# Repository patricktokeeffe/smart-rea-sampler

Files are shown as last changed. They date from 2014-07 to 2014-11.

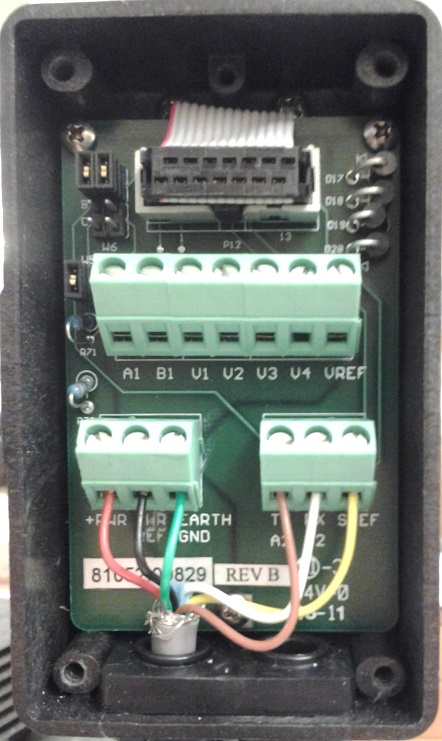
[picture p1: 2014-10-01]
doc/images/sonic_junction_box.jpg

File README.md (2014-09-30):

Long-term Trace Gas Flux Sampler
================================

Using the Relaxed Eddy Accumulation (REA) technique with canisters
------------------------------------------------------------------

> Project page: <https://bitbucket.org/wsular/sampler-rea-lt-canister>

A trace gas sampling system based on the relaxed eddy accumulation technique.
Large (33L) canisters are used as accumulation vessels. 

### License 

This work is licensed under [The MIT License](http://opensource.org/licenses/mit-license.html).

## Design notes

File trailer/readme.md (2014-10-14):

*Trailer-mounted off-grid power system stuffs*

* CAD drawings of
    * window cut into lid of 4x6 plastic project box
    * wood box constructed on small trailer

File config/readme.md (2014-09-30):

*Sensor configuration files*

* GPS :: If the Garmin GPS16x-HVS was not purchased from Campbell Scientific, 
  it must undergo a one-time configuration for use with the datalogger. The
  software required is available for free (see `gps_software_links.txt`) and
  the required settings are saved to an importable format (`gps_settings.cfg').

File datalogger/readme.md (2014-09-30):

Sensors are wired to datalogger as specified in the OpenDocument Spreadsheet 
`wiring_table.ods`. A PDF copy may be obtained from 
[this page](https://bitbucket.org/wsular/sampler-rea-lt-canister/downloads).

The program `default.cr3` is loaded onto the "brains" of the system, a model
CR3000 datalogger produced by Campbell Scientific Inc.

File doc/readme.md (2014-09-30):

This folder contains source files for the user manual. Additional resources 
are available in the `../datalogger`, `../engr`, and `../third-party` folders.

Compiling the user manual requires [Lyx 2.1](https://www.lyx.org). 
Pre-compiled PDF copies of the user manual are available on the project
[downloads](https://bitbucket.org/wsular/sampler-rea-lt-canister/downloads) 
page.

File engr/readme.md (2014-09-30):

*The engineering folder*

* **bill_of_materials.xlsx** is an Excel&trade; spreadsheet listing system
  components, vendors, and prices grouped by category.
* **block_diagrams.odg** contains schematics of various subsystems in block
  format.
* **calculations.xlsx** is an Excel&trade; spreadsheet with various related 
  quantitative analyses. Calculations are categorized and linked across
  worksheets to simplify & facilitate exploration.
    * *Conditions:* environmental conditions specified here
    * *Canisters:* determine actual orifice flow, expected canister fill level
      and potential sampling duration based on canister specs and operating
      conditions
    * *Flow:* **(outdated)** evaluate flow characteristics like delay time,
      [Reynolds #](https://en.wikipedia.org/wiki/Reynolds_number#Transition_and_turbulent_flow),
      frictional pressure drop, and target design pressure downstream of 
      critical orifices
    * *Consumption:* tally the power consumption and duty cycle of components
      to determine power requirements
    * *PV system:* determine required number of solar panels and batteries
      based on their specifications, system power requirements, and operating 
      conditions
    * *Batteries:* derive an expression for battery capacity as a function of
      current draw for use in *PV system* worksheet
* **design_discussion.pptx** is a PowerPoint&trade; document with summary-level
  discussion of the gas sampling design

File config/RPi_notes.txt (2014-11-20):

Raspberry Pi configuration notes
================================

config.txt
----------

* Default user name is "pi" and password is "raspberry" -- root account is 
  disabled so use 'sudo' or 'gksu' when necessary

The suggested `config.txt` was sourced from Adafruit, the vendor.
    https://www.adafruit.com/products/1928
    https://web.archive.org/web/20140930223220/https://www.adafruit.com/products/1928

Real-time clock (RTC) construction
----------------------------------

* Omit the resistors so the module communicates at 3.3V instead of 5V
* Fortuitously all signals are adjacent in the ribbon cable:
    * Pin 3: SDA1
    * Pin 4: 5V
    * Pin 5: SCL1
    * Pin 6: Ground
* Cut cable and split apart so pins 1 & 2 constitute one 'cable' (will be used
  for comms w/ Tri-meter), pins 3-6 are connected as another 'cable' and
  remainder of ribbon cable is left alone for now
* To faciliate easy connect/disconnect, use 4-pc PCB-mount screw terminal block
* Mount on one end of small rectangular IC-style RadioShack PCB; other end will
  be used to mount components for communicating with Trimetric

Initial setup
-------------

For initial setup, connection to internet is required to pull updates and
packages. At WSU, need wifi dongle since wired LAN implements MAC filtering.

* Default local is Great Britain, which does funny things to keyboard layout so
  change to US locale
* Enable I2C support for real-time clock comms (two-part process)

* Run `$ sudo raspi-config` 
    * Under (4) Internationalisation
        * change local from 'en_GB UTF8' to 'en_US UTF8'
        * change timezone to 'US > Pacific-New'
        * change keyboard layout from 'English (UK)' to 'Other > English (US) > English (US)'
            * leave AltGr as default for layout
            * no compose key
            * yes, enable Ctrl+Alt+Bckspc to exit X server
    * Under (8) Advanced Options
        * A6 I2C: change from 'no' to 'yes'
        * A7 Serial: change output message to serial port during boot from 'yes' to 'no'
* Follow Adafruit GPIO setup instructions to finish enabling I2C support
* Follow Adafruit Adding a RTC tutorial to finish integrating RTC w/ RPi

General environment setup
-------------------------

* Get `pip`: run `$ sudo apt-get install python-pip`

Communicating with TriMetric
----------------------------

* Ignore mnfctr's instructions, just use pins 3/4 on trimetric
    * Tie Trimetric and RPi ground together
* DO run signal output through 5->3.3 level converter
* No need to connect transmit from Pi (Trimetric has no Rx)

Communicating with SureSine
---------------------------

* Device uses MODBUS RTU protocol (after switching jumper #4 ON)
* To get Python support for MODBUS run `$sudo pip install -U minimalmodbus`
* `minimalmodbus` uses default baudrate of 115200, must be changed to 9600
* Logical addresses are one greater than real addresses (0x0000=1, 0x0001=2, ...)
  and must be entered as decimal (0x000A=10, 0x000B=11, ...)

Improve usability by enabling VNC server
----------------------------------------

* Follow Adafruit lesson installing/setting up `tightvncserver`; the display
  number specified at launch (":1" argument) causes incoming connections to
  be accepted on port 5900+# (e.g. :1 -> 5901)
* Must configure wired ethernet port (eth0) to use static IP (192.168.174.252)
  so cross-over cable connection is straight-forward
    * <http://www.stuffaboutcode.com/2012/05/raspberry-pi-setting-static-ip-address.html>
    * <http://elinux.org/RPi_Setting_up_a_static_IP_in_Debian>
    * Only include address & netmask under static settings
    * DO need to reboot RPi for settings to take effect

Display mounting
----------------

Resources on the display:
    Overview: https://learn.adafruit.com/hdmi-uberguide/1928-5-display-no-touch-w-slash-mini-driver-800x480-hdmi
    Driver board: https://learn.adafruit.com/hdmi-uberguide/mini-rtd2660-hdmi-driver-board

Concerning the HDMI display buttons:
    Remote control idea: https://forums.adafruit.com/viewtopic.php?f=31&t=53407&p=269909&hilit=button+display+mount#p269909
    Glued pegs/Sugru suggestion: https://forums.adafruit.com/viewtopic.php?f=31&t=34618&p=171226&hilit=button+display+mount#p171226

RS-232 interfacing
------------------

* ~~USB-RS232 converter (Adafruit product 18, discontinued) operates at +/-10Vdc
  which makes it ideal for use with True RS-232 on Inverter's serial dongle
  but NOT okay for communicating via built-in UARTs -- get serial debug cable
  (Adafruit product 954) instead~~ Per MorningStar Connectivity Manual, the
  voltage output of serial ports on MorningStar products is below the RS-232 
  electrical specification so no need to use a special USB-serial adapter with
  SureSine's serial adapter

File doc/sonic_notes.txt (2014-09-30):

- Connect sonic to computer using default serial config: 38400/8/N/1
- Enter menu by sending escape (0x1B) several times
- Change these settings
    * E) Error Handling: 2 -> 1 (exclude -> include invalid data)
    * O) Output rate: 4 -> 10 Hz
    * S) Serial output format: press 1/Custom, 789AB -> 5BE (UVW, Ts, Err code)

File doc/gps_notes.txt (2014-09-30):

- Garmin GPS was purchased from Amazon.com and did not come configured for use
  with CR3000 datalogger
- Connect GPS to computer using RS-232/USB converter, 12Vdc adapter and a
  device built previously but not well documented --> TODO
- Begin communication with GPS using "SNSRXCFG.exe" (v2.90)
    * autodetected device at 4800 baud
    * changed settings:
        ~ baud rate 4800 --> 38400
        ~ disable 'Position averaging' (position pinning = averaging per communication w/ CSI)
    * disabled GPGSA, GPGSV, PGRMT; leaves only GPGGA, GPRMC
    * saved new target settings to 'SNSRXCFG.cfg'
    * sent new settings to device
- Tested, confirmed to work with CR3000
- Remove violet, green wires and tin remaining wires

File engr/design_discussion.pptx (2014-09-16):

## Design Updates: September 15, 2014

- Most of the components have arrived; remaining items:
  - PV system
    - solar panels
    - charge controller
    - cables, switches/breakers
    - Mounting hardware
  - Trailer (for PV array + batteries & transporting system)
  - Pump (discussion follows)
  - (?) Pressure gage (following pump discussion)
- Major decision:
  - retain single tube with subsampling into canisters (high power consumption)
  - or sample directly from atmosphere into canisters (low power consumption)

## Under current design:

To ensure turbulent flow in single tube, minimum flow rate (L/min):

Tube size | @ Sea level | Pullman | Denver
Standard ¼” | 11.2 | 12.5 | 13.6
Thick-wall ¼” | 9.1 | 10 | 11
Standard 1/8” | 2.3 | 2.5 | 2.7

To ensure choked flow across orifice, max. downstream pressure (mbar):

Based on.. | @ Sea level | Pullman | Denver
Pressure drops | 484 | 437 | 350
Canister fill safety margin | 434 | 395 | 357

Target pump operating conditions: 2.5 L/min at 400 mbar

## Pump candidates:

Choice assumed in ‘Consumption’ spreadsheet

Mnfctr | Model | Power | Type | Notes
KNF | NPK09DC | 62W | Diaphragm | Barely meets operating conditions
KNF | NPK 018…DC | 130W | Diaphragm | Moderate operating margin
Gast | 15D1150-101-1006 | 13W | Diaphragm | Barely meets operating range; power specs are suspiciously optimistic
Gast | 22D1180-201-1002 | 96W | Diaphragm | Narrow operating margin
Gast | 1531-107B-G617 | 170W | Rotary vane | Very wide operating margin; power specs missing, reported value is from pump with similar characteristics
Gast | LOA-101-JR | ~120W | Rocking piston | Moderate operating margin Power specs are 11-15V @ 9A Finicky: temp range (5-40 ºC), RH range (20-80%)
Gast | ROA-V210-JH / ROA-P201-JH | 170W | Rocking piston | Wide operating margin; Finicky: temp range (5-40 ºC), RH range (20-80%)
Air Dimensions | J161-xx-HH0 | 29W | Diaphragm | Barely almost hardly meets operating conditions
Air Dimensions | 201-xx-JH0 | 460W | Diaphragm | Barely meets operating conditions; power specs missing, reported value is from 222 series (dual head version of 221-)
Air Dimensions | 221-xx-JH0 | 460W | Diaphragm

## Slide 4

With indicated pump choice, the solar array would need to be about 1000W to provide 365/24/7 operation. However:
- pump indicated is probably insufficient to achieve turbulent flow
- larger pump raises the req'd array size EX: the other KNF model listed is 130W -> raises array to 1800W
Can we lower system power consumption to minimize solar array size?
- Sure, mitigation strategies include:
  - Seasonal instead of year-round operation
  - Not operating at night
  - Bye-days
  - Deploy at lower latitudes (this is destined for CA, right?)
- Other ideas:
  - Modify sampling configuration (discussion begins next slide)
  - Automatic generator back-up (yuck)
  - Small wind-turbine generator (except for possibly disrupting wind field?)

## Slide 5

One alternative:

- move orifices/3-way valves to sampling location (diagram)
- use small dual-head pump to draw air across orifices such as Brailsford TD-4X2N (pictured)
  - with heads in series, it produces sufficient vacuum for choked flow (measured @ -19 in Hg ≈ -650 mb)
  - small power consumption (0.4A @ 9-14Vdc) eliminates need to power pump directly off PV array batteries

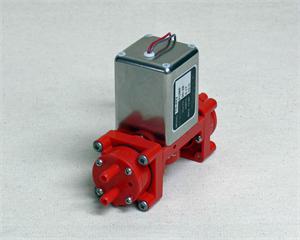
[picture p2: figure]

to pump
(normally open)

negligible-length
1/8" leader tube

orifice (common)

Buy another pressure sensor?:
To detect pump/diaphragm failure, and to ensure sufficient vacuum is present for choked flow, add a pressure sensor between each pump & 3-way valve.
One electronic 0-15 psia gage (Omega PX309-015G5V) is available but one more would be required at an estimated $240.

to canister
(normally closed)

P

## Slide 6

Relocating orifice/3-way valve assembly to near sonic sampling volume introduces volume between canister & orifice. However, this volume is negligible.
Even under the following assumptions, volume of tube from 3-way valve to canister is less than 1% of actual volume in canister:
- 10% safety margin (canister filled to 42.8% of capacity or about 14 std L)
- 30 ft of standard 1/4" tubing
With 20 ft of 1/8" standard, volume in tubing is 0.02% of final sample volume.

Volume (mL) as a function of tube size, length:

Tube size | 10 ft | 15ft | 20 ft | 25 ft | 30 ft
Standard 1/4" | 37 | 56 | 75 | 94 | 113
Thick-wall 1/4" | 25 | 37 | 49 | 61 | 74
Standard 1/8" | 1.5 | 2.2 | 3.0 | 3.7 | 4.5

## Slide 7

Smart REA Sampler
Collection Mode

- Identical systems for ‘up’ and ‘down’ sampling.
- Critical orifice mounts in common side of solenoid valve.
- Pressure gauge #1 needs to work across wide range… something like <0.1 psia to 30 psia.
- Pressure gauge #2 operates under vacuum, so general purpose 0-15 psia is satisfactory.
- Manual valves must be leak tight in vacuum, and solenoid must seal under same conditions.
- Tubing downstream of solenoid is 1/8" Teflon.
- Fittings from valve(s) to canister are stainless steel.
- Filter probably needed upstream of pump (not shown).

Air parcel

Switching

3

P2

To
Pump

Open

P1

Open

Closed

Sampling
Canister

Legend
Manual, High Integrity On/Off Valve
High Precision Critical Orifice
High Precision Vacuum/Pressure Gauge
Fast, Low Dead Space Three-Way Valve

P

3

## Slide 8

Open to Pump

Smart REA Sampler
Pressurization Mode

3

To
Pump

Closed
to Pump

P2

From
Regulated
Gas Cylinder

Closed

- After sampling period, canister is filled to ~30 psi with UHP nitrogen.
- Pressure gauge records pressure change so that the dilution factor is precisely known.

P1

Open

Open

Sampling
Canister

Legend
Manual, High Integrity On/Off Valve
High Precision Critical Orifice
High Precision Vacuum/Pressure Gauge
Fast, Low Dead Space Three-Way Valve

P

3

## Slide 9

Open to Pump

Smart REA Sampler
Transfer Mode

- Pressurized main canister is used to fill several smaller canisters/cartridges.
- Cartridges are attached in parallel so that all are filled to same pressure.
- Cartridges can be then transferred to laboratory for analysis.
- Pressure gauge records pressure change so that the cartridge pressures are known.
- Cartridge design still TBD.

Legend
Manual, High Integrity On/Off Valve
High Precision Critical Orifice
High Precision Vacuum/Pressure Gauge
Fast, Low Dead Space Three-Way Valve

3

To
Pump

Closed
to Pump

Closed
to Pump

Closed

P2

To
Pump

To Smaller
Evacuated
Cartridges

P1

Open

Open

Sampling
Canister

P

3

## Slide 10

Open to Pump

Smart REA Sampler
Evacuation Mode

3

To
Pump

Closed
to Pump

Closed
to Pump

Open

P2

To
Pump

To Suitable
Vacuum
Pump

- Vacuum pump must be able to evacuate system to near vacuum (< 0.1 psi = 7 mb).
- ~~Solenoid also evacuated to minimize contamination.~~

P1

Open

Open

Sampling
Canister

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

P

3

## Design Updates: June 11, 2013

- Contacted Tom Jobson & Claudia Toro about borrowing canisters. Claudia will work with Korey to get trained up on how to evacuate/fill them.
- New design for the switching mechanism. Swapped critical orifice with switching valve and changed switching valve to three-way valve. Other arm of three-way valve will be tied to vacuum pump.
  - Flow will be passing through the critical orifice at all time, addressing concern about transient flows through the orifice.
  - Dead volume less of a concern now. Instead, we just need to have a very good understanding of the expected travel time from the tower top to the three way valve. Note Patrick’s concern below.
- Patrick O’Keefe asked how we “anticipate handling the time delay between the measurement of an up/down eddy at the sonic and the switching of the appropriate valve down at the canister? Will the flow be regulated well-enough to use a static pre-calculated delay time? Seems like the switching should occur at the sonic to avoid that ambiguity.”

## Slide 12

From
Tower

Smart REA Sampler
Collection Mode

- Identical systems for ‘up’ and ‘down’ sampling.
- Need to minimize dead volume between solenoid and critical orifice.
- Pressure gauge needs to work across wide range… something like <0.1 psi to 30 psi.
- Manual valves must be leak tight in vacuum, and solenoid must seal under same conditions.
- All tubing & fittings downstream of solenoid are stainless steel.
- Filter needed upstream of solenoid (not shown).

OLD DESIGN 1

To
Pump

S

P

Sampling
Canister

Open

Open

Closed

Switching

Legend
Manual, High Integrity On/Off Valve
High Precision Critical Orifice
High Precision Vacuum/Pressure Gauge
Fast, Low Dead Space Solenoid Valve

P

S

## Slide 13

From
Tower

Smart REA Sampler
Collection Mode

- Identical systems for ‘up’ and ‘down’ sampling.
- Need to minimize dead volume between solenoid and critical orifice.
- Pressure gauge needs to work across wide range… something like <0.1 psi to 30 psi.
- Manual valves must be leak tight in vacuum, and solenoid must seal under same conditions.
- All tubing & fittings downstream of solenoid are stainless steel.
- Filter needed upstream of solenoid (not shown).

OLD DESIGN 2

To
Pump

Switching

3

To
Pump

Open

P

Open

Closed

Sampling
Canister

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

P

3

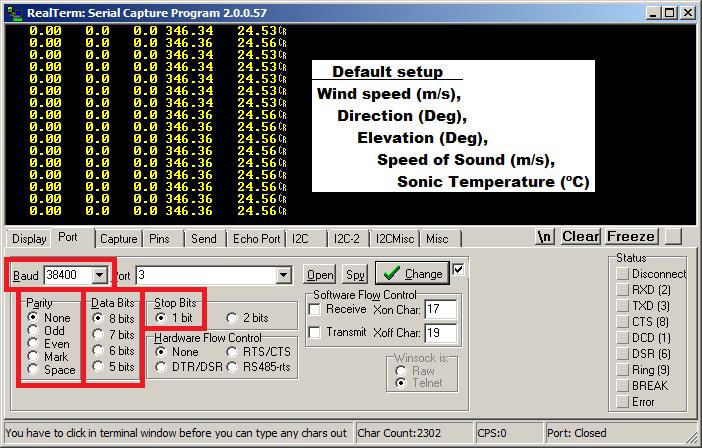
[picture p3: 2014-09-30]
doc/images/sonic_defaults.png

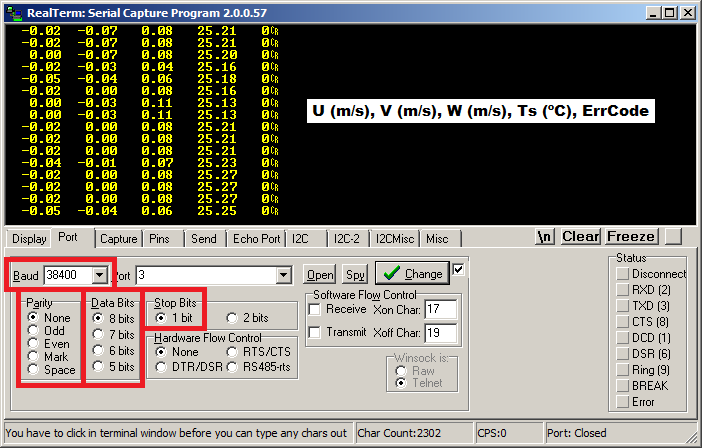
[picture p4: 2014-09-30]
doc/images/sonic_settings.png

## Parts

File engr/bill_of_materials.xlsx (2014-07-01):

Component List for REA/Canister System
 |  |  |  | Total ($): | $19689.57
Description | Qnty | Vendor (Mnfctr if diff.) | Model / Part no. | Unit price ($) | Ext. price ($) | Price as of | Notes | Online
Anemometer, 3D ultrasonic | 1 | RM Young | 81000VRE | 3390 | 3390 |  |  | http://www.youngusa.com/products/6/46.html
Canisters, SS, 33L | 2 | LabCommerce Inc | X133L | 1700 | 3400 | 2014-06-27 |  | http://www.labcommerce.com/airsamp_viewproducts.php?catid=17
Critical orifice, screened sapphire, 6sccm | 2 | O'Keefe Controls | JSS-3-SS | 37.5 | 75 | 2013-07-02 |  | http://www.okcc.com/catsub_precision.htm
Data logger | 1 | Campbell Scientific | CR3000-ST-SW-RC-NC | 3235 | 3235 |  |  | http://www.campbellsci.com/cr3000
Data logger memory/ethernet module | 1 | Campbell Scientific | NL115-ST-SW | 290 | 290 |  |  | http://www.campbellsci.com/nl115
Datalogger charger: 12->24V | 1 | Digikey (CUI Inc) | 102-3188-ND | 44.48 | 44.48 | 2014-06-27 |  | http://www.digikey.com/product-detail/en/PYB15-Q24-S24-T/102-3188-ND/4477446
Datalogger support software, PC400 | 1 | Campbell Scientific | PC400 |  | 0 |  | *Ask Patrick
Enclosure for canisters | 1 | Home Depot (Rubbermaid) | 1863391 | 224 | 224 | 2014-06-27 | "Rattan Patio Cabinet" | http://www.homedepot.com/p/Rubbermaid-Rattan-Patio-Cabinet-1863391/204725829?N=5yc1vZbtz1
Enclosure for datalogger | 1 | Campbell Scientific | ENC12/14 |  | 0 |  |  | http://www.campbellsci.com/enc-12-14-overview
Enclosure for MFC + valve relays | 1 | Walmart (Plano) | Guide Series Poly. Box, Large | 39.99 | 39.99 | 2014-06-27 |  | http://www.walmart.com/ip/Plano-Guide-Series-PolyCarbonate-Box-Large-Blue/20563433
Fittings, assorted | 1 | Swagelok |  | 200 | 200 | -- n/a --
Fittings: cross, 1/4" | 2 | Swagelok | SS-400-4 | 42.54 | 85.08 | 2014-06-27
Fittings: |  | Swagelok |  |  | 0
Fittings: |  | Swagelok |  |  | 0
Fittings: port connectors, 1/4" | 8 | Swagelok | SS-401-PC | 5.9 | 47.2 | 2014-06-27
Fittings: tee, 1/4" x 1/4" FNPT x 1/4" | 2 | Swagelok | SS-400-3-4TTF | 33.74 | 67.48 | 2014-06-27
Fittings: union, 1/4" x 1/8" MNPT | 4 | Swagelok | SS-400-1-2BT | 8.18 | 32.72 | 2014-06-27
Fittings: union, bulkhead, 1/4" | 2 | Swagelok | SS-400-61 | 17.08 | 34.16 | 2014-06-27
GPS receiver | 1 | Amazon (Garmin) |  | 89 | 89 | 2014-06-27 | For precision time source | http://www.amazon.com/Garmin-010-00258-63-GPS-16x-HVS/dp/B0016NYHSG
GPS receiver magnetic mount | 1 | Amazon (Garmin) |  | 13 | 13 | 2014-06-27 |  | http://www.amazon.com/Garmin-010-10302-00-Magnetic-mount/dp/B00006B6MD/ref=pd_bxgy_e_text_y
Mass flow controller | 1 | Alicat Scientific | MC-20SLPM-D | 1330 | 1330
Mass flow controller AC/DC adapter | 1 | Alicat Scientific | PVPS24U | 52.25 | 52.25
Mass flow controller data cable | 1 | Amazon (Cables2Go) | 02318 | 7.62 | 7.62 | 2014-06-27 | 8-pin mini DIN | http://www.amazon.com/C2G-Cables-02318-Mini-Din-Charcoal/dp/B0002GWN84
Mass flow controller pre-filter | 1 | Swagelok | SS-4F-40 | 77.83 | 77.83 | 2014-06-27
Memory card, CompactFlash, 8GB | 2 | California PC |  | 154 | 308 | 2014-06-27 |  | http://www.californiapc.com
Pressure sensor, 0-30psia, 0-5V output | 2 | Omega | PX409-030A5V | 525 | 1050 |  |  | http://www.omega.com/pptst/PX409_Series.html
Pressure snubber | 2 | Omega | PS-4G | 13 | 26 |  |  | http://www.omega.com/pptst/PS_SNUBBERS.html
Pump, 12Vdc | 1 | KNF Inc. | NPK09DC | 400 | 400
Relay, 5-60Vdc output, 0-5Vdc logic | 2 | Opto22 | ODC5 | 16 | 32 | 2014-06-30 | For valve control | http://opto22.com/site/pr_details.aspx?cid=7&item=ODC5
Relay mounting board | 1 | Opto22 | PB4R | 45 | 45 | 2014-06-27
Relay, solid state, 5-60Vdc output, 0-5Vdc logic | 1 | Crydom |  | 0 | 0 | 2014-06-30 | For pump on/off
Relay, solid state, cover | 1 |  |  |  | 0
Solar array battery bank package | 1 | Wholesale Solar | 1898531 | 1543 | 1543 | 2014-06-30
Solar charge regulator | 1 | MorningStar | SS-10L-12V | 75 | 75
Solar panels | 2 | Wholesale Solar |  |  | 0
Temp/RH sensor | 1 | Campbell Scientific (Vaisala) | HMP155A-L20 | 685 | 685 |  |  | http://www.campbellsci.com/hmp155a
Temp/RH sensor radiation shield | 1 | Campbell Scientific (RM Young) | 41005-5 | 200 | 200 |  |  | http://www.campbellsci.com/h41005-5
Tower, 3m | 1 | Campbell Scientific | UT10 | 565 | 565 |  |  | http://www.campbellsci.com/ut10
Tubing, PFA, 1/4" OD (0.047" wall), 100 ft | 1 | Swagelok |  | 270 | 270 | 2014-06-27
Tubing, PFA, 1/4" OD (0.047" wall), 100 ft | 1 | Savillex | 760-1-156-250-100 | 327.6 | 327.6 | 2014-06-27
Valve, diaphragm, manual, two-way | 6 | Swagelok | 6LVV-DPRS4 | 203.69 | 1222.14 | 2014-06-27 | For canisters
Valve, solenoid, 12V, three-way, fast-acting | 2 | Paramount Supply (Asco) | 8320G041DC12/DCD | 103.01 | 206.02 |  | For conditional eddy sampling
 |  |  |  |  | 0
 |  |  |  |  | 0
 |  |  |  |  | 0
 |  |  |  |  | 0
Valve, solenoid, 12V, three-way, fast-acting | 0 | Parker-Hannifin | 091-0094-900 | 285 | 0 | 2012-07-18
Tubing, PFA, 1/8" OD (1/16" ID), 100' | 0 | Savillex | 760-1-062-125-100 | 171.6 | 0 | 2014-06-27 |  | http://www.savillex.com/ProductDetail.aspx?ProductName=Coiled-tubing-PFA-116-ID-x-18-OD-100
 |  |  |  |  | 0
 |  |  |  |  | 0
 |  |  |  |  | 0
 |  |  |  |  | 0
 |  |  |  |  | 0
 |  |  |  |  | 0
 |  |  |  |  | 0
 |  |  |  |  | 0
 |  |  |  |  | 0

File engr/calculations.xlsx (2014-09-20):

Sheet: Conditions
Reference
Barometric pressure
sea level | 1013 | mbar
Pullman (2550') | 923 | mbar
Denver (5280') | 834 | mbar
User Input
Ambient temperature | 55 | ºF
Barometric pressure | 923 | mbar

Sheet: Canisters
Conditions
Ambient temperature | 55 | ºF
Barometric pressure | 923 | mbar
User Input
Orifice flow @ STP | 6 | sccm
Canister volume | 33 | liters
Canister full safety margin | 10%
Deadband | 0.85 | (multiplier)
Sampling hours per day | 24 | hrs
Derived Values
Actual orifice flow | 6.4 | cc/min
Fraction of time in deadband | 60.46749138%
Fraction of time per canister | 19.76625431%
Canister fill time | 7.75 | days

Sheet: Flow
 |  |  | Flow | Velocity | Delay | Delay (# scans) |  |  | Friction
Conditions |  |  | L/min | m/s | s | 10Hz | 20Hz | Reynolds # | factor | ΔP (mbar) | ΔF (%)
Ambient temperature | 55 | ºF | 1 | 34.22680103 | 0.18 | 1.8 | 3.6 | 1682.824725 | 0.049 | 2.15 | 1.20
Barometric pressure | 923 | mbar | 1.5 | 51.34020154 | 0.12 | 1.2 | 2.4 | 2524.237087 | 0.045 | 1.94 | 0.80
 |  |  | 2 | 68.45360206 | 0.09 | 0.9 | 1.8 | 3365.649449 | 0.041 | 1.81 | 0.60
Reference |  |  | 2.5 | 85.56700257 | 0.07 | 0.7 | 1.4 | 4207.061811 | 0.039 | 1.71 | 0.48
Pressure drop across MFC | 7 | psi | 3 | 102.6804031 | 0.06 | 0.6 | 1.2 | 5048.474174 | 0.037 | 1.63 | 0.40
Tubing size | I.D. |  | 3.5 | 119.7938036 | 0.05 | 0.5 | 1.0 | 5889.886536 | 0.036 | 1.57 | 0.34
1/4" (0.047) | 0.156 | in | 4 | 136.9072041 | 0.04 | 0.4 | 0.9 | 6731.298898 | 0.035 | 1.52 | 0.30
1/4" (0.062) | 0.126 | in | 4.5 | 154.0206046 | 0.04 | 0.4 | 0.8 | 7572.71126 | 0.034 | 1.47 | 0.27
1/8" (0.047) | 0.031 | in | 5 | 171.1340051 | 0.04 | 0.4 | 0.7 | 8414.123623 | 0.033 | 1.44 | 0.24
 |  |  | 5.5 | 188.2474057 | 0.03 | 0.3 | 0.6 | 9255.535985 | 0.032 | 1.40 | 0.22
User input |  |  | 6 | 205.3608062 | 0.03 | 0.3 | 0.6 | 10096.94835 | 0.032 | 1.37 | 0.20
Tubing inner diameter | 0.031 | in | 6.5 | 222.4742067 | 0.03 | 0.3 | 0.5 | 10938.36071 | 0.031 | 1.35 | 0.18
Tubing length | 20 | ft | 7 | 239.5876072 | 0.03 | 0.3 | 0.5 | 11779.77307 | 0.030 | 1.32 | 0.17
ΔP across valve | 50 | mbar | 7.5 | 256.7010077 | 0.02 | 0.2 | 0.5 | 12621.18543 | 0.030 | 1.30 | 0.16
Turbulence threshold (Re#) | 4100 |  | 8 | 273.8144082 | 0.02 | 0.2 | 0.4 | 13462.5978 | 0.029 | 1.28 | 0.15
 |  |  | 8.5 | 290.9278087 | 0.02 | 0.2 | 0.4 | 14304.01016 | 0.029 | 1.26 | 0.14
Derived values |  |  | 9 | 308.0412093 | 0.02 | 0.2 | 0.4 | 15145.42252 | 0.028 | 1.24 | 0.13
Air temperature | 12.8 | degC | 9.5 | 325.1546098 | 0.02 | 0.2 | 0.4 | 15986.83488 | 0.028 | 1.22 | 0.13
Density of air | 1.125 | kg/m^3 | 10 | 342.2680103 | 0.02 | 0.2 | 0.4 | 16828.24725 | 0.028 | 1.21 | 0.12
Dynamic viscosity of air | 1.800940656e-05 | Pa*s | 10.5 | 359.3814108 | 0.02 | 0.2 | 0.3 | 17669.65961 | 0.027 | 1.19 | 0.11
Tubing cross-section area | 0.0008 | in^2 | 11 | 376.4948113 | 0.02 | 0.2 | 0.3 | 18511.07197 | 0.027 | 1.18 | 0.11
Tubing volume | 2.97 | mL | 11.5 | 393.6082118 | 0.02 | 0.2 | 0.3 | 19352.48433 | 0.027 | 1.17 | 0.10
Tubing volume fraction | 0.02% |  | 12 | 410.7216123 | 0.01 | 0.1 | 0.3 | 20193.89669 | 0.027 | 1.15 | 0.10
ΔP across MFC | -482.58 | mbar (diff) | 12.5 | 427.8350129 | 0.01 | 0.1 | 0.3 | 21035.30906 | 0.026 | 1.14 | 0.10
ΔP across orifice+valve | -485.656 | mbar (diff) | 13 | 444.9484134 | 0.01 | 0.1 | 0.3 | 21876.72142 | 0.026 | 1.13 | 0.09
Max pressure for choked flow | 487.344 | mbar (abs) | 13.5 | 462.0618139 | 0.01 | 0.1 | 0.3 | 22718.13378 | 0.026 | 1.12 | 0.09
Max pressure @ pump inlet | 435.636001 | mbar (abs) | 14 | 479.1752144 | 0.01 | 0.1 | 0.3 | 23559.54614 | 0.026 | 1.11 | 0.09
Max pressure @ canisters | 395.044 | mbar (abs) | 14.5 | 496.2886149 | 0.01 | 0.1 | 0.2 | 24400.95851 | 0.025 | 1.10 | 0.08
Target design pressure | 395.044 | mbar (abs) | 15 | 513.4020154 | 0.01 | 0.1 | 0.2 | 25242.37087 | 0.025 | 1.09 | 0.08
Constants
Gas constant, dry air | 287.058 | J/(kg K)
Sutherland's formula (air): C | 120 | K
Sutherland's formula (air): λ | 1.512041288 | (μPa*s)/K^-1/2
Choked flow ratio (P2/P1) | 0.528
Unit conversion: mbar/kPa | 10 | unity
Unit conversion: mbar/psi | 68.94 | unity
Unit conversion: in/m | 39.37 | unity
Unit conversion: s/min | 60 | unity
Unit conversion: L/m^3 | 1000 | unity
Unit conversion: in/ft | 12 | unity
Unit conversion: ft/m | 3.281 | unity
Unit conversion: Pa/kPa | 1000 | unity
Unit conversion: mL/in^3 | 16.387064 | unity

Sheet: Consumption
 |  |  |  |  |  |  | Running power | 17.55962054 | W
 |  |  |  |  |  |  | Standby power | 3.132 | W
Component | Model (Make) | Rating description | Qnty | Volts | Amps | Power, W | Run time | Total, W
Datalogger | CR3000 | 10-16Vdc; current depends | 1 | 12 | 0.010 | 0.12 | 100% | 0.12 | Core devices
Datalogger ethernet module | NL115 | depends; worst case: 43 mA @ 12Vdc | 1 | 12 | 0.043 | 0.516 | 100% | 0.52
GPS receiver | GPS16x-HVS | 8-40Vdc @ 65mA | 1 | 12 | 0.065 | 0.78 | 100% | 0.78
Pressure sensor | PX409-030A5V | 10-30Vdc @ 10mA | 2 | 12 | 0.010 | 0.12 | 100% | 0.24
Solar regulator | SunSaver | per CSI tech note: 6-10 mA continuously | 1 | 12 | 0.010 | 0.12 | 100% | 0.12
Sonic anemometer | 81000VRE | 12-24Vdc @ 110mA max | 1 | 12 | 0.110 | 1.32 | 100% | 1.32
Temp/RH sensor | HMP155A | 7-28Vdc @ <=3mA | 1 | 12 | 0.003 | 0.036 | 100% | 0.04
Fast-acting valve | (Parker) | 12Vdc @ 1000mA | 2 | 12 | 1.000 | 12 | 19.76625431% | 4.74 | Off in stand-by
Valve control relay | ODC5 | 12mA @ logic voltage (1mA off-state leakage) | 2 | 5 | 0.012 | 0.06 | 19.76625431% | 0.02
Pump control relay | ODC5 | 12mA @ logic voltage (1mA off-state leakage) | 1 | 5 | 0.012 | 0.06 | 100% | 0.06
Pump | Brailsford | 9-14Vdc @ 0.4A | 2 | 12 | 0.400 | 4.8 | 100% | 9.60

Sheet: PV system
Max consumption | 17.6 | W | Temp. derating multiplier [1] |  |  | Reference
 | 1.5 | Amps | Degrees | Degrees |  |  | sun hours/day
Standby consumption | 3.1 | W | F | C | Multiplier | Location | annual mean | winter
 | 0.3 | Amps | 80 | 26 | 1 | Pullman, WA | 4 | 2 | [5, 6], [4]
 |  |  | 70 | 21.2 | 1.04
 |  |  | 60 | 15.6 | 1.11
Operating conditions |  |  | 50 | 10 | 1.19
Running hours of pump per day | 24 | hr/day | 40 | 4.4 | 1.3
Watt hours needed per day | 421.430893 | W*hr/day | 30 | -1.1 | 1.4
 |  |  | 20 | -6.7 | 1.59
Battery bank requirement [1,2] |  |  | Selected battery characteristics
Battery bank voltage | 12 | V | Type | Rolls Surrette S-550
Days without sun | 10 | days | Voltage | 6 | Volts
Depth of discharge | 50% |  | Amp-hour | 726.7489942 | Ahr
Temperature multiplier | 1.59 |  | Number of | 4 | batteries
Battery bank size | 1116.791866 | A*hr | Total reserve | 1453.497988 | Ahr
 |  |  | Req'd # | 4 | batteries
Solar array sizing (annual mean) [2] |  |  | Selected PV panel characteristics
Sun hours per day | 4 | hr/day | Make | Solarland
Generation requirement | 105.3577232 | W/hr | Model | SLP150S-12
Required # of solar panels | 1 | panels | Vmp | 18 | Volts
Max amperage to PV controller | 8.34 | Amps | Imp | 8.34 | Amps
 |  |  | Voc | 21.6 | Volts
Solar array sizing (winter worst-case) [2] |  |  | Isc | 9.17 | Amps
Sun hours per day | 2 | hr/day | Rated power | 150 | Watts
Generation requirement | 210.7154465 | W/hr | Actual power | 120.096 | Watts
Required # of solar panels | 2 | panels
Max amperage to PV controller | 16.68 | Amps | Selected charge controller characteristics
 |  |  | Make | MorningStar Corp.
 |  |  | Model | SunSaver SS-10-12V
Charge controller rating |  |  | Max amperage | 10 | Amps
Safety factor | 20% |  | Max voltage | 30 | Volts
Annual mean | 10.425 | Amps | Regulated at | 14.4 | Volts
Worst case | 20.85 | Amps
Wire size requirements [3]
Max voltage across wire | 18 | Volts
[1] http://rimstar.org/renewnrg/sizing_select_batteries_for_off_grid_solar_system.htm
[2] http://pdf.wholesalesolar.com/Download%20folder/System_Worksheet.pdf
[3] http://rimstar.org/renewnrg/solar_voltage_drop_table_calculator_wire_sizing_for_dc.htm
[4] http://pvwatts.nrel.gov/pvwatts.php
[5] http://www.ecy.wa.gov/climatechange/maps/solar/solar_state.pdf
[6] http://www.nrel.gov/gis/images/map_pv_national_hi-res_200.jpg

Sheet: Batteries
Amp-Hours | Amps | Rolls S-550 deep cycle battery
554 | 5.54
524 | 7.28
500 | 10
441 | 18.37
428 | 21.4
401 | 26.76
381 | 31.74
364 | 36.38
342 | 42.8
317 | 52.79
300 | 59.92
278 | 69.55
253 | 84.17
218 | 109.14
154 | 154.08

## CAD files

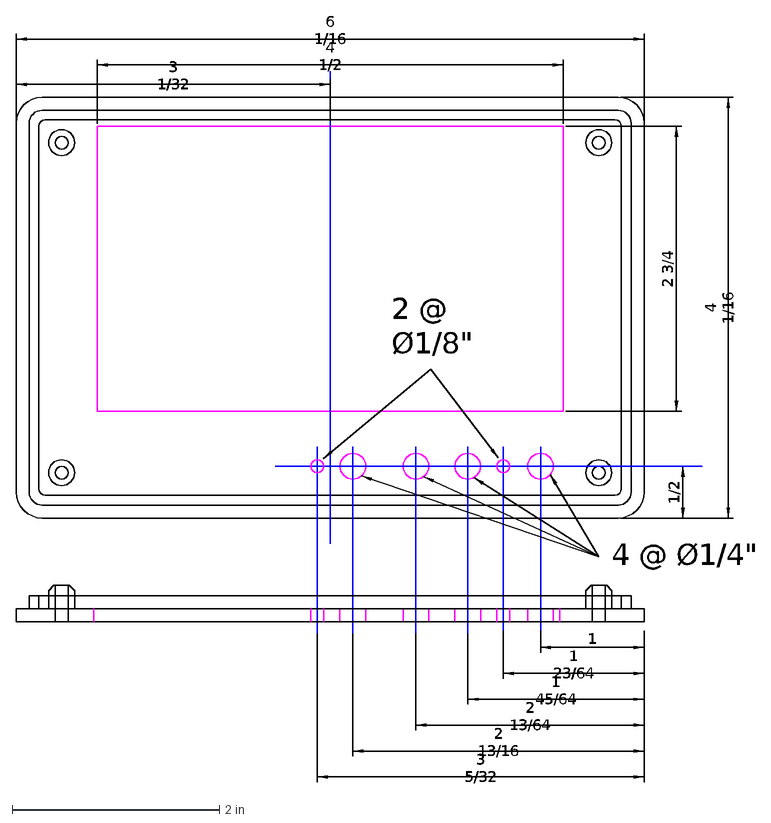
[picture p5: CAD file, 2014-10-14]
trailer/Display_mount_4x6_lid.dxf
1
1 23/64
1 45/64
2 13/64
2 13/16
3 5/32
1/2
4 1/2
3 1/32
4 @ Ø1/4"
2 @ Ø1/8"
6 1/16
4 1/16
2 3/4

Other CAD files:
trailer/Trailer_box.dxf

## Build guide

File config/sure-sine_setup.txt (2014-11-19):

Notes regarding Sure-Sine inverter setup
----------------------------------------

* Communication software is freely available from MorningStar; use new download
  script added to `/third-party/` folder
* Jumper settings, change before applying power:
    * Switch #1 ON to enable 'standby' power mode 
    * Switch #4 ON to change comms from MeterBus(TM) to MODBUS

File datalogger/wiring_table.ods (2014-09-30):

User-facing connections
Device |  | Channel | Color | CR3000 Port | OR
Sonic anemometer (81000VRE) |  | Data receive (Rx) | white | COM4 Tx (C7)
 |  | Data transmit (Tx) | brown | COM4 Rx (C8)
 |  | Data reference (G) | yellow | G
 |  | Power input | red | 12V
 |  | Power reference | black | G
 |  | Earth ground | green | earth
 |  | Shield | bare | earth
GPS receiver (GPS16x-HVS) |  | PPS signal | gray | COM3 Tx (C5)
 |  | Data transmit (Tx) | white | COM3 Rx (C6)
 |  | Power input | red | 12V
 |  | Power ground | black | G
 |  | Power switch | yellow | G
 |  | Data receive (Rx) | blue | G or earth
 |  | Shield | clear | G or earth
T/RH probe (HMP 155A) |  | Temp. signal | yellow | DF 13 H
 |  | RH signal | blue | DF 14 H
 |  | Signal reference | white | DF 13 L & 14 L
 |  | Power input | red | 12V
 |  | Power ground | black | G
 |  | Shield | clear | earth
Pressure transducers | Canister (UP) | Excitation (+) | red | SW12V-1
 |  | Common (-) | black | G | DF 6 L
 |  | Signal (+) | white | SE 11 | DF 6 H
 |  | Shield | bare | G or earth | jump to L
 | Canister (DOWN) | Excitation (+) | red | SW12V-1
 |  | Common (-) | black | G | DF 7 L
 |  | Signal (+) | white | SE 13 | DF 7 H
 |  | Shield | bare | G or earth | jump to L
Internal connections
Device |  | Channel | Color | CR3000 Port | OR
Pressure transducers | Pump (UP) | Excitation (+) | red | SW12V-2
 |  | Common (-) | black | G | DF 1 L
 |  | Signal (+) | white | SE 1 | DF 1 H
 |  | Shield | bare | G or earth | jump to L
 | Pump (DOWN) | Excitation (+) | red | SW12V-2
 |  | Common (-) | black | G | DF 2 L
 |  | Signal (+) | white | SE 3 | DF 2 H
 |  | Shield | bare | G or earth | jump to L
 | Barometric | Excitation (+) | red | 12V
 |  | Common (-) | black | G | DF 8 L
 |  | Signal (+) | white | SE 15 | DF 8 H
 |  | Shield | bare | G or earth | jump to L
Relay control |  | Activate up-valve |  | C1
 |  | Activate down-valve |  | C2
 |  | Activate pump |  | C3
 |  | Common (-) |  | G

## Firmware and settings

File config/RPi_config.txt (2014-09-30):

# suggested config.txt from vendor (https://www.adafruit.com/products/1928)

# uncomment if you get no picture on HDMI for a default "safe" mode
#hdmi_safe=1

# uncomment this if your display has a black border of unused pixels visible
# and your display can output without overscan
#disable_overscan=1

# uncomment the following to adjust overscan. Use positive numbers if console
# goes off screen, and negative if there is too much border
#overscan_left=16
#overscan_right=16
#overscan_top=16
#overscan_bottom=16

# uncomment to force a console size. By default it will be display's size minus
# overscan.
#framebuffer_width=1280
#framebuffer_height=720

# uncomment if hdmi display is not detected and composite is being output
hdmi_force_hotplug=1

# uncomment to force a specific HDMI mode (here we are forcing 800x480!)
hdmi_group=2
hdmi_mode=1
hdmi_mode=87
hdmi_cvt 800 480 60 6 0 0 0

# uncomment to force a HDMI mode rather than DVI. This can make audio work in
# DMT (computer monitor) modes
#hdmi_drive=2

# uncomment to increase signal to HDMI, if you have interference, blanking, or
# no display
#config_hdmi_boost=4

# uncomment for composite PAL
#sdtv_mode=2

#uncomment to overclock the arm. 700 MHz is the default.
#arm_freq=800

# for more options see http://elinux.org/RPi_config.txt

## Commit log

2014-06-27 Check-in initial design documents from Tim
    [CanisterDesign.xlsx]
2014-06-27 Check-in component cost spreadsheet
    [components.ods]
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2014-06-28 Update & clean up formatting of components spreadsheet
    [components.xlsx]
2014-06-28 Create spreadsheet of flow characteristics (Re#, lag time, press drop, etc)
    [flow_characteristics.xlsx]
2014-07-01 Add pump, PV battery bank to components spreadsheet
    [components.xlsx]
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2014-07-01 Add to components: relay & cover for pump control
    [components.xlsx]
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2014-07-01 Add flow variance due to variable presence of flow through orifices
    [flow_characteristics.xlsx]
2014-07-13 Add preliminary size calculations for PV array, battery bank
    [power.ods]
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2014-07-22 Create 1-page insert for datalogger enclosure with wiring details
    [wiring_table_insert.ods]
2014-09-09 Convert power calc spreadsheet to MS office format
    I don't really want to do this but for the sake of consistency with
    the corporate software environment of this laboratory, it must be so.
    [power.ods, power.xlsx]
2014-09-12 Revise flow characteristics spreadsheet
    - Specify actual measured pressure drop across orifice+3-way valve as
    pressure drop across MFC (this is a realistic, not minimum value)
    - Increase resolution of calculated values table
    - Change barometric pressure sea level -> Pullman (1976 std. atmos.)
    [flow_characteristics.xlsx]
2014-09-12 Improve canister behavior calculations
    - Use volumetric flow rate instead of mass flow across orifice when
    determining canister fill time
    - See how ambient conditions affect fill time
    - Change canister max fill ratio to safety margin
    [CanisterDesign.xlsx]
2014-09-13 FIX: revise power calcs with fraction of time valves are active
    Previous calcs assumed both 3-way valves activate 100% of sampling
    time. In reality, only one of two is active and only when wind speed
    is not within deadband.
    [power.xlsx]
2014-09-13 Revise calculation of req'd batteries
    If specified 6V batteries, require an even number. If 12V batteries,
    round calculated number up (ceiling) instead of nearest integer.
    [power.xlsx]
2014-09-15 ENH: combine calculation spreadsheets into single workbook
    - Unify impact of ambient conditions (temp, press)
    - Unify impact of sampling hours per day (canister fill, power consumption)
    - Revise PV system calcs to be more conservative w.r.t battery bank
    [CanisterDesign.xlsx, calculations.xlsx, flow_characteristics.xlsx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]
2014-09-15 Refine flow calculations
    - Permit user-specified turbulence threshold (but still use 4100 Re#)
    - Incorporate pressure drop across 3-way valve
    - Separately determine pressure drop across MFC and orifice+valves and
    use greater pressure drop when evaluating max. pump inlet pressure
    - Determine design pump inlet pressure using greater pressure drop and
    maximum canister pressure
    [calculations.xlsx]
2014-09-16 Calculate fraction of final sampling volume represented by tubing
    Revised design has long tubing between canisters and 3-way valves at
    sampling point. Internal volume of tube depends on tube diameter and
    length. Calculations show even a 30 ft length of standard 1/4" tubing
    has an internal volume representing less than 1% of the final sample
    volume at 10% safety margin (approx 14L).
    [calculations.xlsx]
2014-09-16 Revise system config presentation with research & revised config proposal
    Current design results in high power consumption, mostly from pump
    which flushes sample down tower to canisters/orifices/3-way valves.
    Particular issues and revised proposal are added to the PowerPoint
    presentation.
2014-09-16 ENH: specify battery capacity as a function of current draw
    Using mnfctr spreadsheet, determine best-fit of capacity (amp-hours) as a
    function of current draw (amps) and use that formula in PV array calcs.
    [calculations.xlsx]
2014-09-18 Create block diagram and detailed list of components for small PV array
    Also includes preliminary list of additional components if we retain the
    remote pump design.
    [calculations.xlsx]
2014-09-20 Revise calcs with slightly smaller solar panel
    Low power consumption design was approved. Select solar panel with
    slightly smaller power output and physical dimensions to better match
    power consumption and to fit better on a smaller trailer (4x6 not 5x8).
    [calculations.xlsx]
2014-09-20 FIX: Revise calcs using actual power generated & decrease solar panel size
    Since charge controller is pulse-width modulation, actual power produced
    is determined by battery voltage and available current through PV array.
    Update calculations to use the actual instead of rated power when
    evaluating req'd number of solar panels.
    Also check to ensure solar panel output voltage falls within ratings of
    charge controller.
    And since low power consumption design was approved, select solar panel
    with smaller power output and physical dimensions to better match
    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
    [calculations.xlsx]
2014-09-20 FIX: separate valve control relays from pump relays in power calcs
    The valve control relays operate at 20% duty level but pump relay runs
    all the time while in sampling mode. Impact on power consumption is
    negligible.
    [calculations.xlsx]
2014-09-30 CLN: relocate non-user-manual-documents, remove stale files
    Most documents currently in 'doc' folder are part of the design
    process, not end-user documentation so relocate to 'engr' folder.
    Since wiring table is directly associated with datalogger, it ends
    up in new logger-specific directory.
    Documents which are now irrelevant are removed.
    [bill_of_materials.xlsx, wiring_table.ods]
2014-09-30 Update datalogger wiring to reflect revised sampling configuration
    [wiring_table.ods]
2014-09-30 Configure GPS for operation with CR3000 datalogger
    Notes will be folded into appendix of user manual. Links document
    and binary blob are for future convenience.
    [gps_settings.cfg]
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2014-09-30 Implement half-hour stats of anemometer data
    - Add framework for periodic statistics
    - Use half-hour per convention
    - Adjust WD for sonic orientation or set to NAN if bad data
    - TO FIX:
    * number of records in data tables
    * user-specifiable sonic orientation (azimuth)
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2014-10-14 Add CAD drawing of enclosure lid to mount HDMI display in
    A plastic 4"x6" Radioshack enclosure will be used to house the
    Raspberry PI HDMI display. The lid needs a window cut out and
    several holes drilled for button access.
    [Display_mount_4x6_lid.dxf]
2014-10-14 Add CAD drawing of wooden box mounted on trailer
    [Trailer_box.dxf]
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2014-11-20 FIX/DOC: correct note about RS-232 voltages on SureSine serial adapter
